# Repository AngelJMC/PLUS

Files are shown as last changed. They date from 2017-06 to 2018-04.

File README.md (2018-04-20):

# Otto DIY +
"Otto DIY with steroids" 

This Repository have all open source files for Otto DIY+ an interactive robot that anyone can make!,
Otto DIY + can make everything that Otto DIY does + Bluetooth + APP + switch + sensors + strength +... anything you might create
Is completely open source, Arduino compatible, 3D printable, once you have all components and tools you will be able to build your own Otto


This is a more advanced version requires some expertise and patience, if you want to start slow as a beginner  please go to [Otto DIY repository](https://github.com/OttoDIY/DIY)

Start by downloading all files here.

### Customized version

This custom version includes:
1. Lithium battery with micro USB charger and 5v step-up module.
2. MG90S servos
3. A touch sensor with two pushbutton.

Video: https://youtu.be/i325EG5CZ8M

## For the hardware
Gather all the off the shelf parts in the BOM file that you'll need for this assembly, then 3d print the latest .stl files and then follow the instruction manual to build your own robot.

## For the programming
1. Download & Install Arduino IDE: https://www.arduino.cc/en/Main/Software also this driver if you have a clone board: http://www.wch.cn/download/CH341SER_EXE.html for PC, or http://www.wch.cn/download/CH341SER_MAC_ZIP.html for MAC
2. Copy all libraries to C:\Users\user\Documents\Arduino\libraries (or wherever your library folder is installed):
3. Open  for example OTTO_smooth_criminal.ino, make sure in tools you have "Board: Arduino Nano" "Processor ATmega328" and your Otto is connected to the corresponding port
4. Upload code to your Otto and will dance!
5. Make your own dance just modify the program using same functions

### Otto DIY + is  design using Autodesk Fusion 360
So is completely parametric and precise to adjust tolerances
[You can modify it for customization](https://gallery.autodesk.com/fusion360/projects/otto-diyplus) or further improvements!

Special thanks to all #Ottobuilders that made and are making this project evolve:
Davor Levstek 
jarsoftelectrical
Juan Felix Mateos
Loreman
Gerardo Barbarov Rostan
Javier Isabel
G4alileo
Obijuan
tritri62
Octavio P Nogueira
Gustavo Reynaga
Rafael López
Frank Lopez
Jason Snow
Pablo E. García Palacios
Marco
Liao Ping Lun
Jayesh Chauhan
If we skip one please tell us!

## License CC-BY-SA
<br /><span xmlns:dct="http://purl.org/dc/terms/" property="dct:title">Otto DIY</span> by <a xmlns:cc="http://creativecommons.org/ns#"  property="cc:attributionName"> [ottodiy.com](http://ottodiy.com) </a> is licensed under a <a rel="license" href="http://creativecommons.org/licenses/by-sa/4.0/">Creative Commons Attribution-ShareAlike 4.0 International License</a>.

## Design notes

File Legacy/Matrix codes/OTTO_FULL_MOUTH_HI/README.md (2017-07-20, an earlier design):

# Otto DIY PLUS

This Repository have all open source files for my version of the popular Otto DIY PLUS with the OTTO welcome on 7219MAX MATRIX LED mouth
The Arduino code is modified from the Zowi robot and original OTTO code, it has modified to work with a MAX 7219 LED MATRIX as as mouth as well as other software adjustments.

Please copy all the files in the Library folder to the Arduino IDE Library folder

The main program is inside the OTTO_FULL_MOUTH_HI folder, ensure you are using the latest version of the Arduino IDE.

Happy roboting....

Otto was inspired by another robot BoB the BiPed and programmed using code from [another open source biped robot Zowi](https://github.com/bqlabs/zowi)

## License CC-BY-SA
<br /><span xmlns:dct="http://purl.org/dc/terms/" property="dct:title">OttoDIY</span> by <a xmlns:cc="http://creativecommons.org/ns#" href="ottobot.org" property="cc:attributionName" rel="cc:attributionURL">ottobot.org</a> is licensed under a <a rel="license" href="http://creativecommons.org/licenses/by-sa/4.0/">Creative Commons Attribution-ShareAlike 4.0 International License</a>.

Otto's differences are in the assembled size (11cm x 7cm x12cm), cleaner integration of components and expressions. 
Using off the shelf and 3D printed parts, simple electronics connections (almost no welding required), and basic coding skills, [you will be able to build your own cute Otto friend in as little as two hours!](http://www.instructables.com/id/Otto-Build-You-Own-Robot-in-Two-Hours/)

### Otto is design using Autodesk 123D Design software 
[You can modify it for customization](http://www.123dapp.com/Project/Otto-build-your-own-robot/5658683) or further improvements!
Gather all the off the shelf parts in the [BOM file] (https://github.com/OttoDIY/Otto/blob/master/OTTO_V02_BOM_STP_STL/OTTO_BOM.xlsx) that you'll need for this assembly, then follow [the instruction manual] (https://github.com/OttoDIY/Otto/blob/master/OTTO_V02_BOM_STP_STL/OTTO_InstructionManual_V02.pdf)

This robot is licensed under a Creative Commons Attribution-ShareAlike 4.0 International License. Please read the LICENSE files for more details.

More info in http://ottobot.org

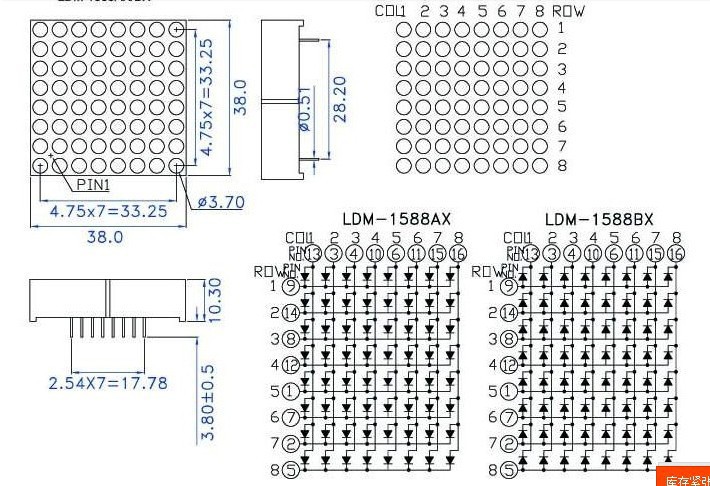
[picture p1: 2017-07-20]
Documents/3-75MM-8-8-red-dot-16P-1588BS-Dimensions-38-38LED-dot-matrix-module.jpg

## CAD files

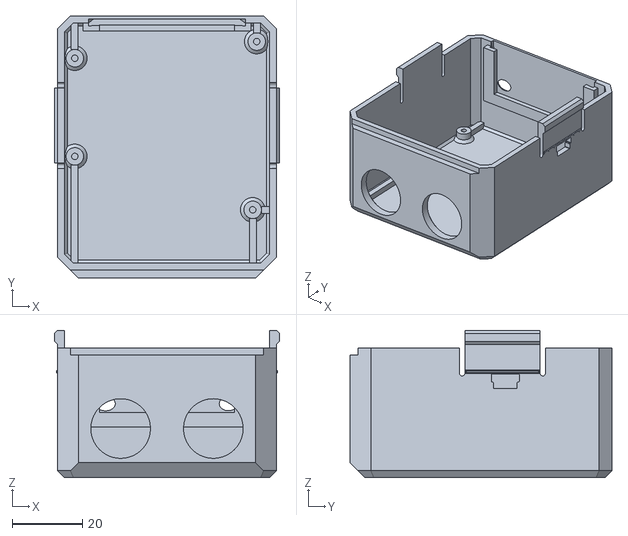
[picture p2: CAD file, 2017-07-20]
3D print/OTTO_Head_MATRIX_MG90S.stl
64.3 x 74.7 x 42.0

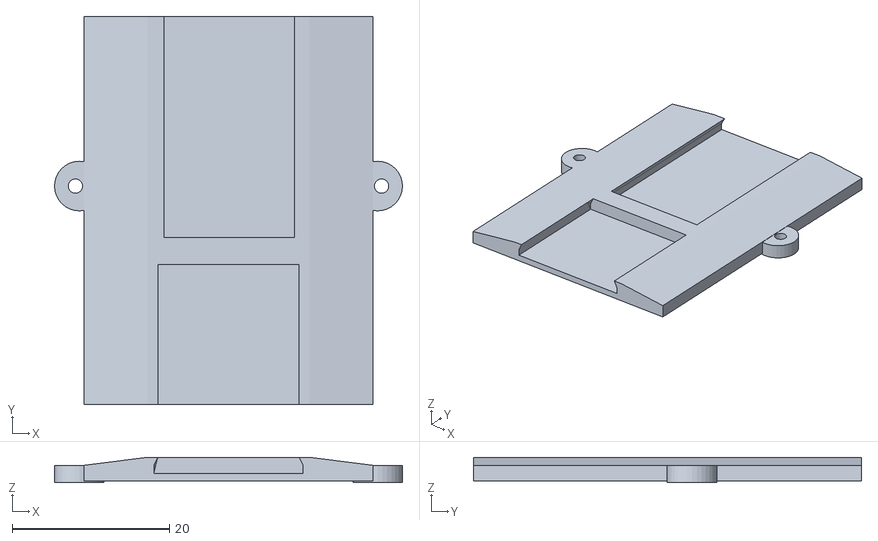
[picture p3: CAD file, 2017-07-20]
3D print/OTTO_battery_MG90S.stl
44.3 x 49.4 x 3.22

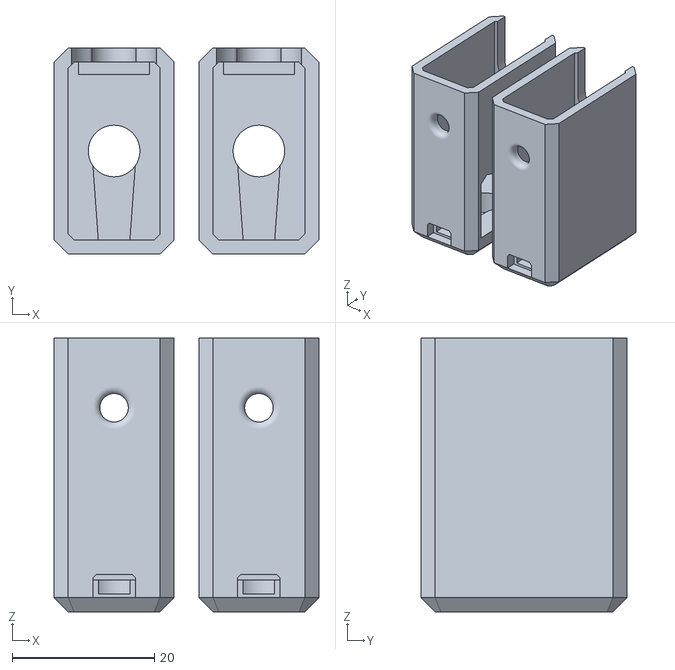
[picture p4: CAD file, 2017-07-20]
3D print/OTTO_legs_MG90s.stl
37.2 x 29.0 x 38.5

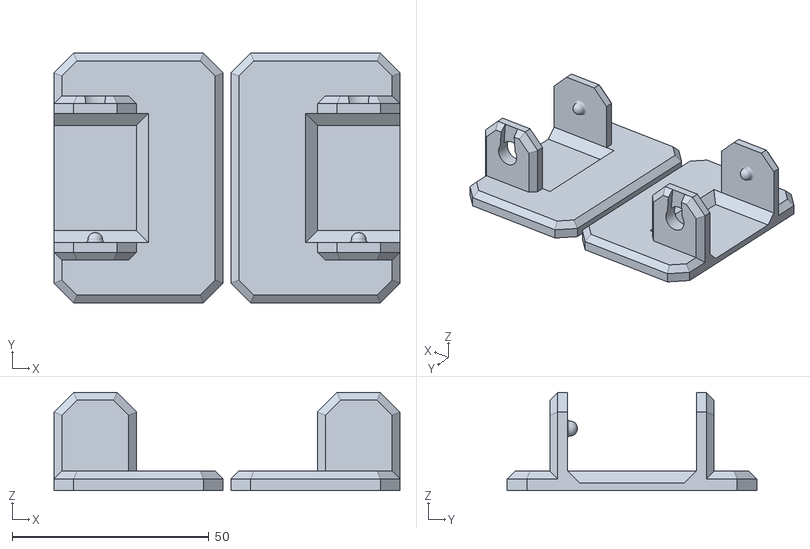
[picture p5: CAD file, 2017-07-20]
3D print/OTTO_feet_MG90S.stl
88.0 x 63.5 x 25.0

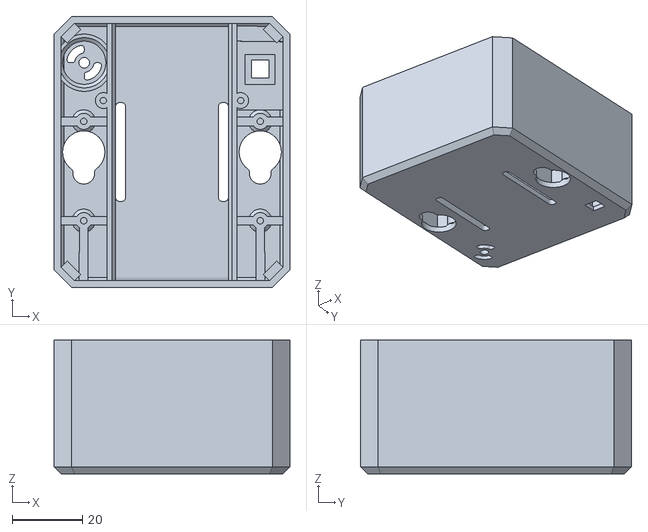
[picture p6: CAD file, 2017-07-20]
3D print/OTTO_Body_MATRIX_MG90S.stl
67.0 x 77.0 x 38.0

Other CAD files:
3D print/Blender3D/OTTO_Body_Matrix_v6.blend
3D print/Blender3D/body.blend
3D print/Blender3D/head.blend

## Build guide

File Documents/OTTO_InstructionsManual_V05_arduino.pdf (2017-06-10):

# DIY

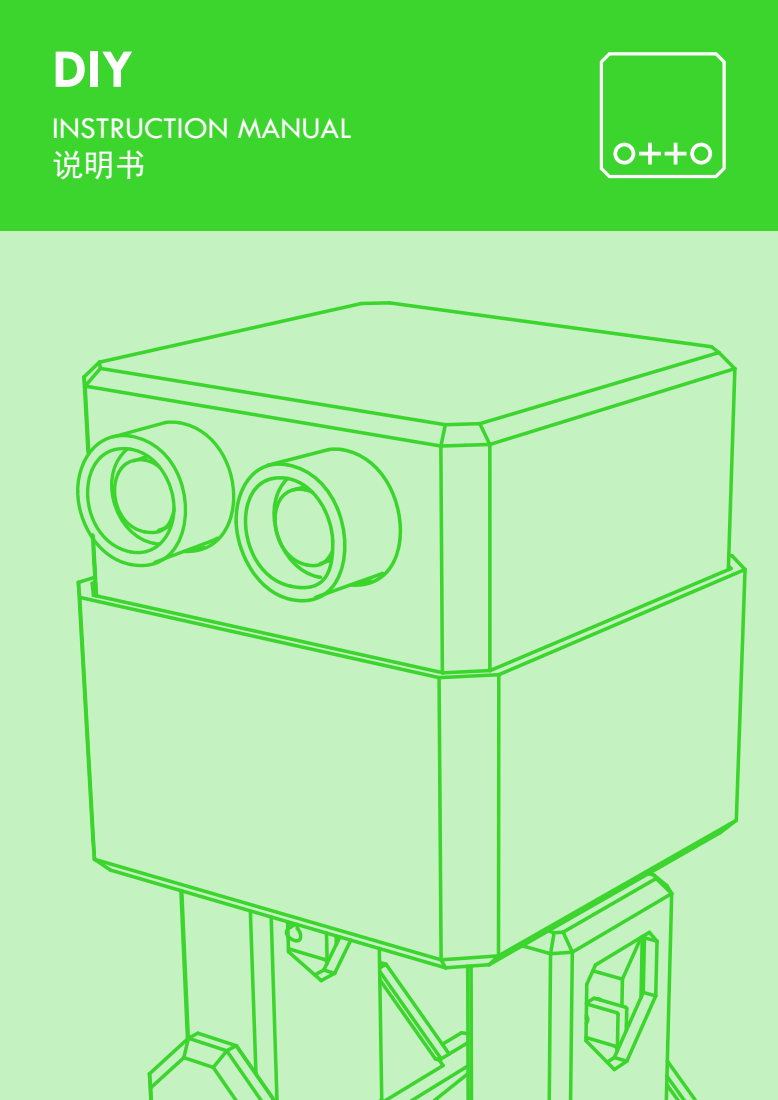
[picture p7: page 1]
INSTRUCTION MANUAL 说明书

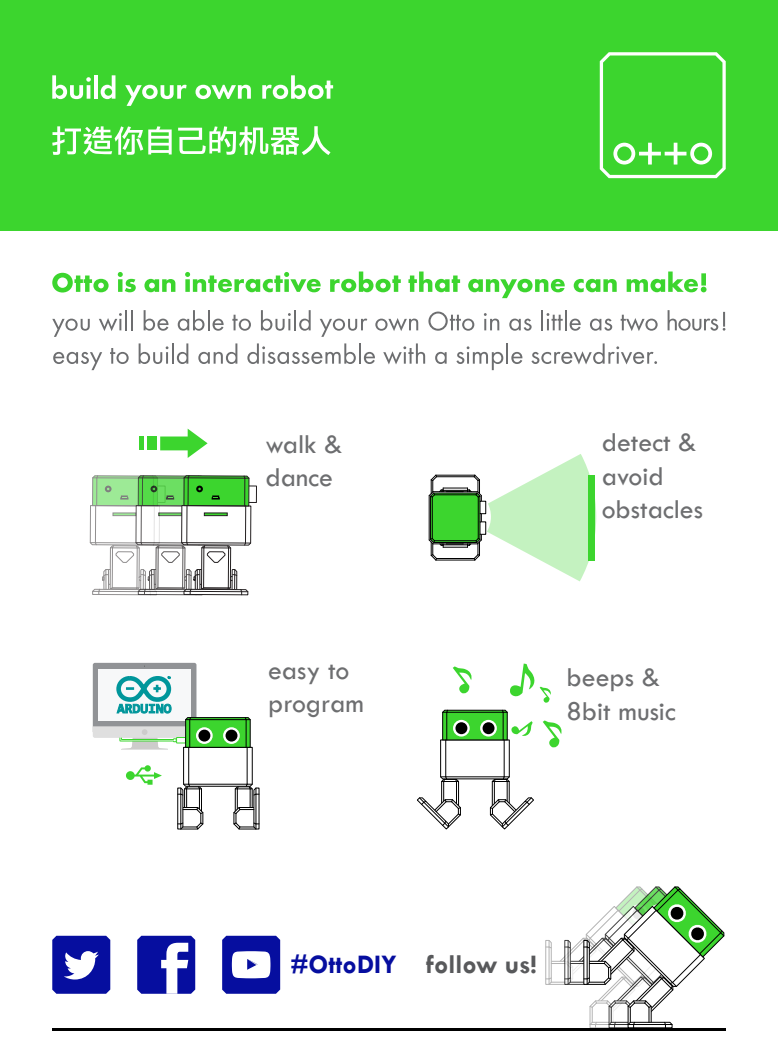
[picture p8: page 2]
beeps & 8bit music; detect & avoid obstacles; walk & dance; easy to program

#OttoDIY follow us!

# PARTS

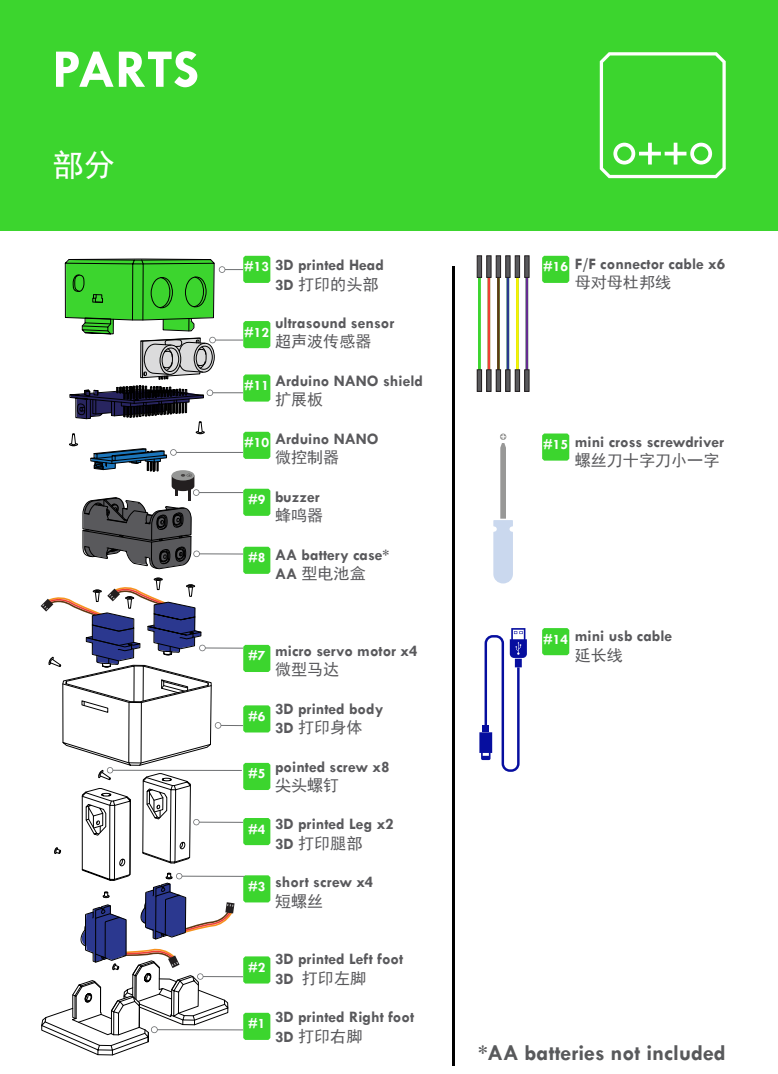
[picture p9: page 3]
#13 3D printed Head 3D 打印的头部; ultrasound sensor 超声波传感器; Arduino NANO shield 扩展板; Arduino NANO 微控制器; buzzer 蜂鸣器; micro servo motor x4 微型马达; 3D printed body 3D 打印身体; pointed screw x8 尖头螺钉; 3D printed Leg x2 3D 打印腿部; short screw x4 短螺丝; 3D printed Left foot 3D 打印左脚; #16 F/F connector cable x6 母对母杜邦线; mini cross screwdriver 螺丝刀十字刀小一字; mini usb cable 延长线

AA battery case*
AA 型电池盒

3D printed Right foot
3D 打印右脚 #1

*AA batteries not included

a

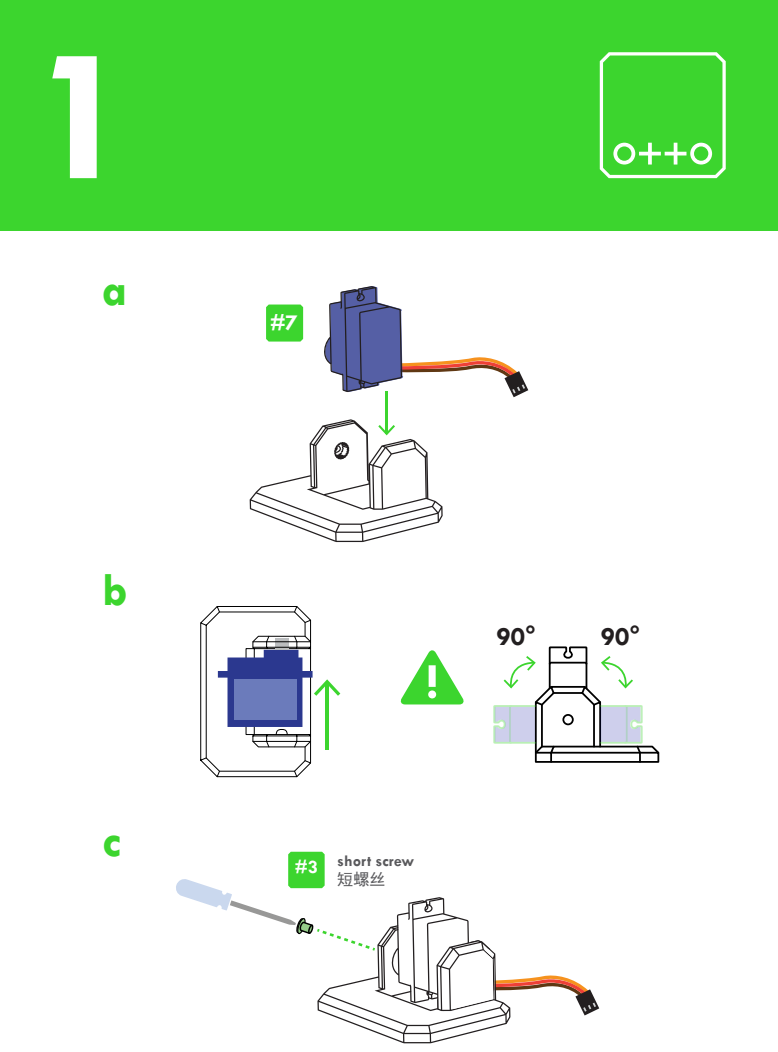
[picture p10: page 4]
short screw 短螺丝

a

a

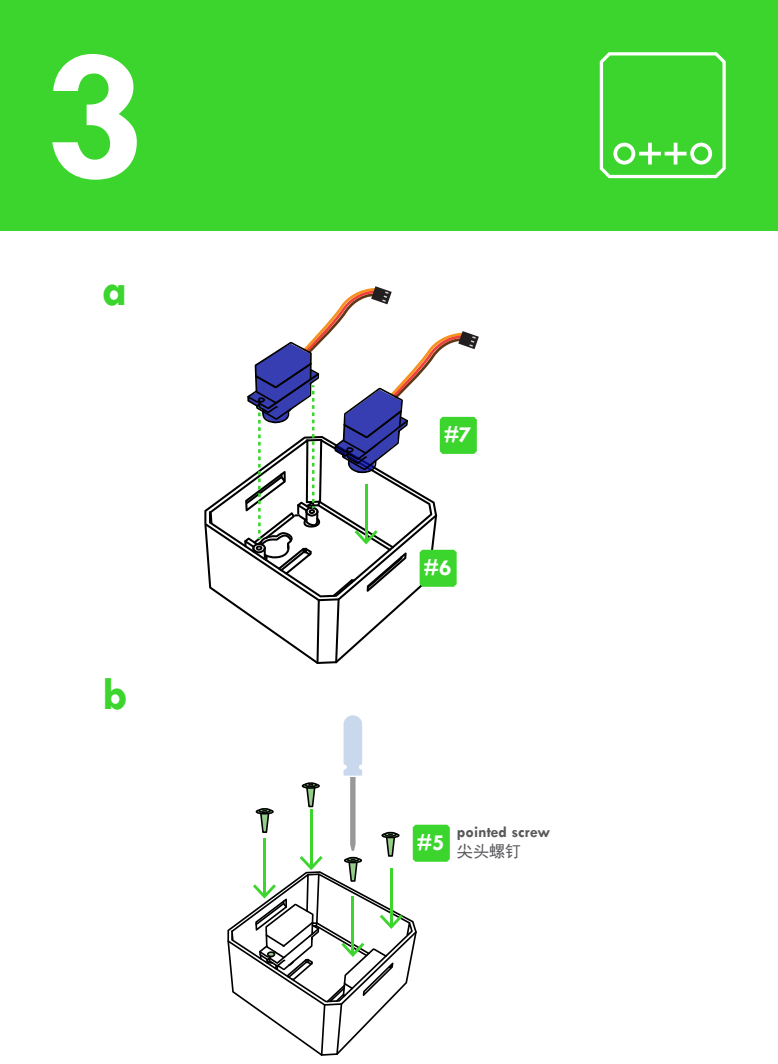
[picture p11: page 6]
#5 pointed screw 尖头螺钉

a

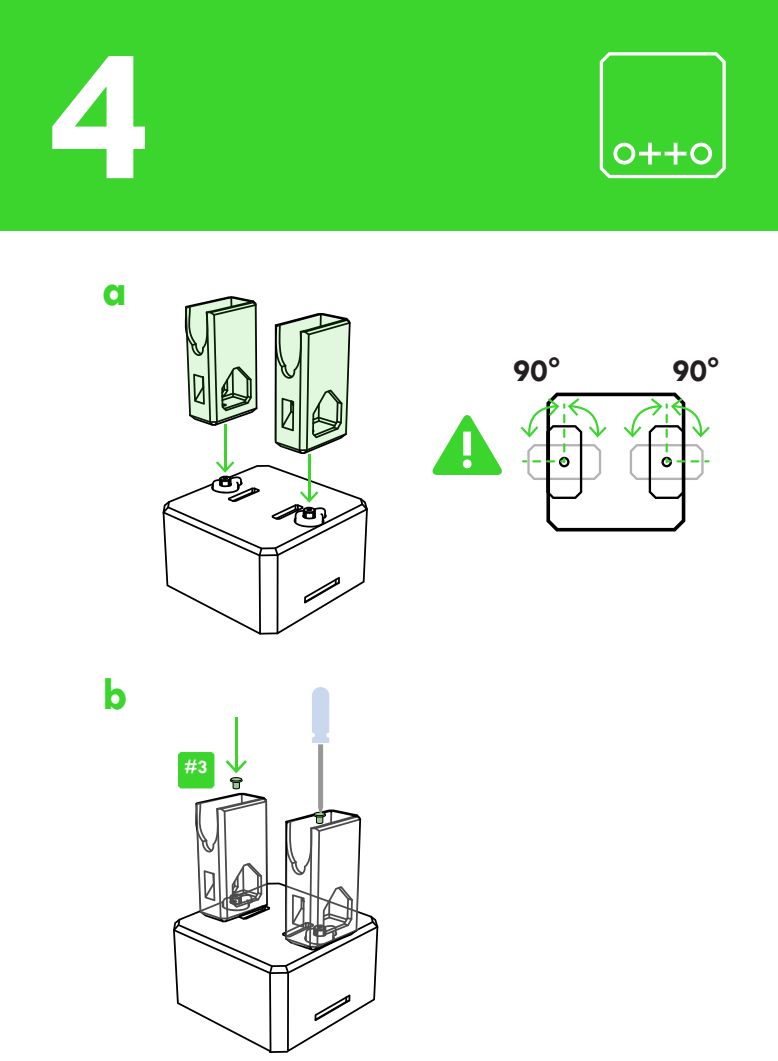
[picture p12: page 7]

ab

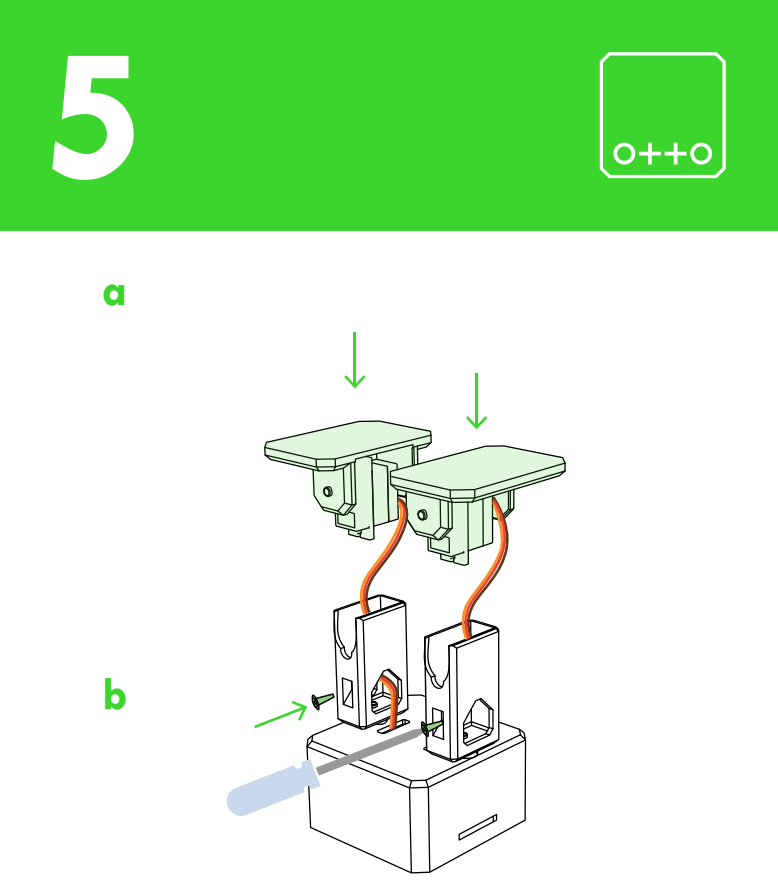
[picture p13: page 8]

ab

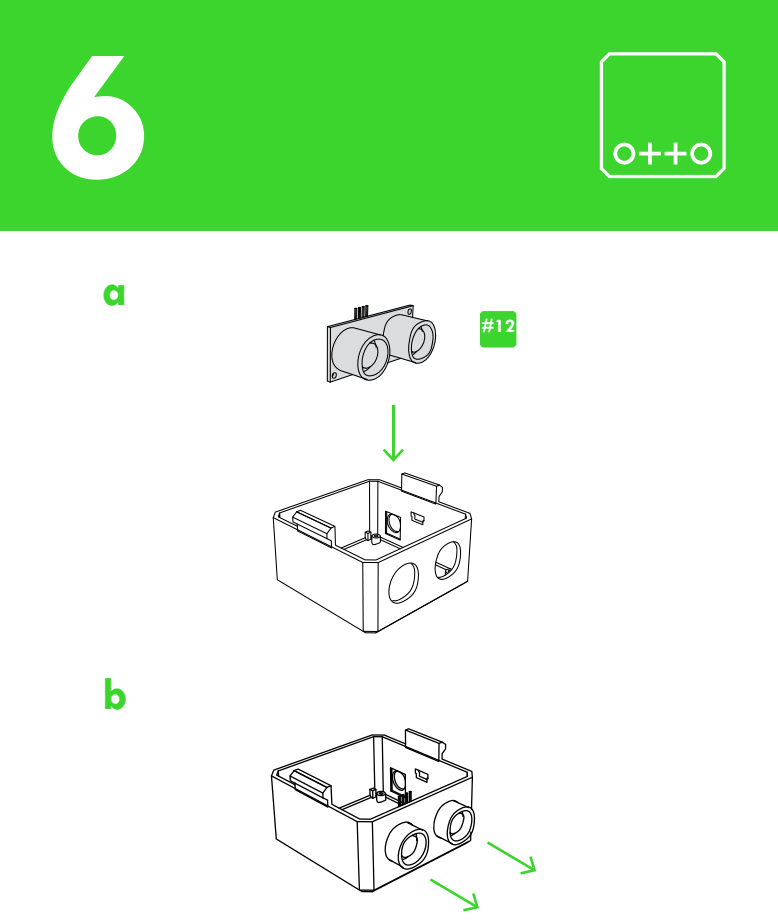
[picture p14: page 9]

ab

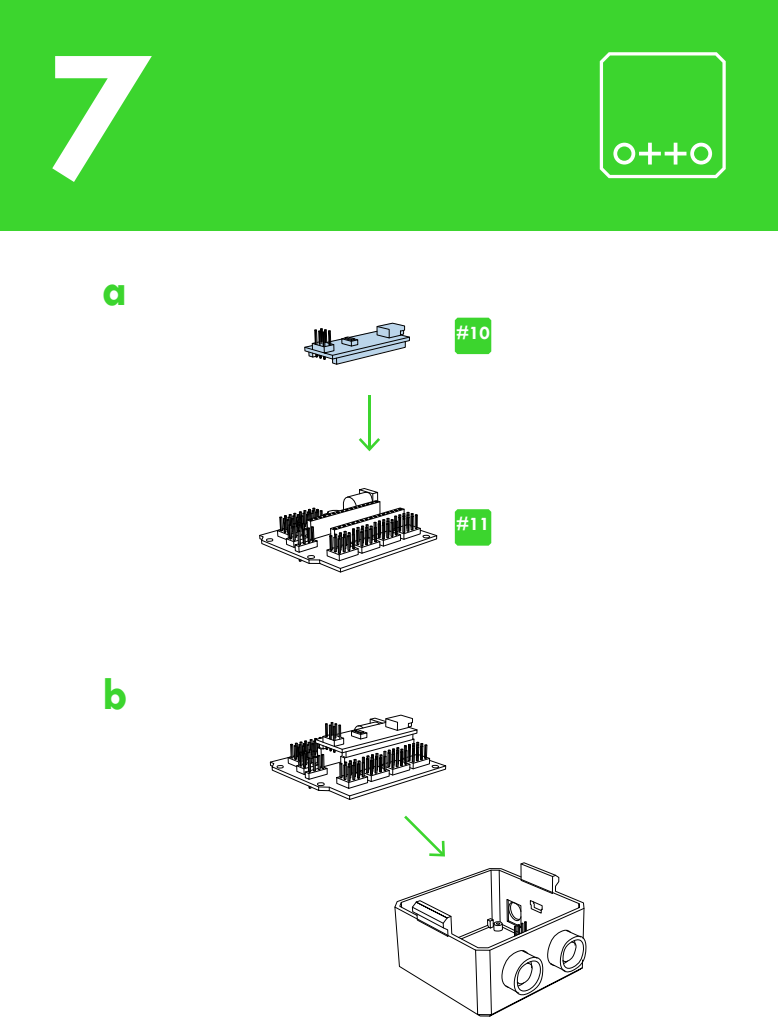
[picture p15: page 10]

ab

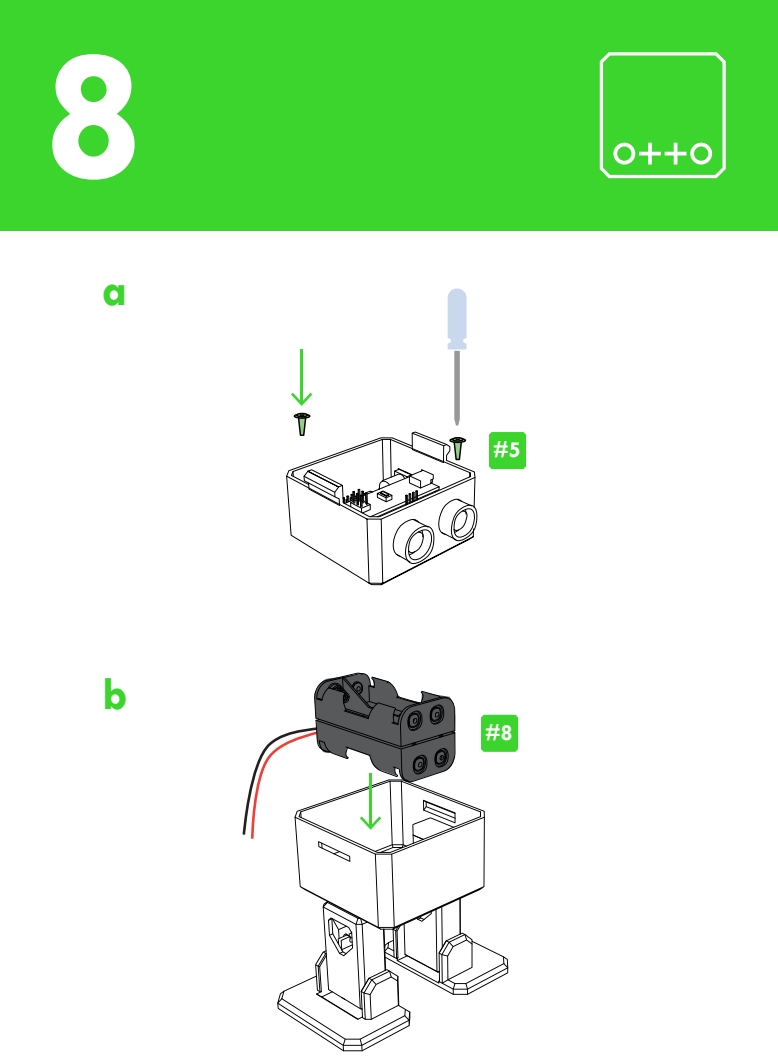
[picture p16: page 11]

*cable colors may vary

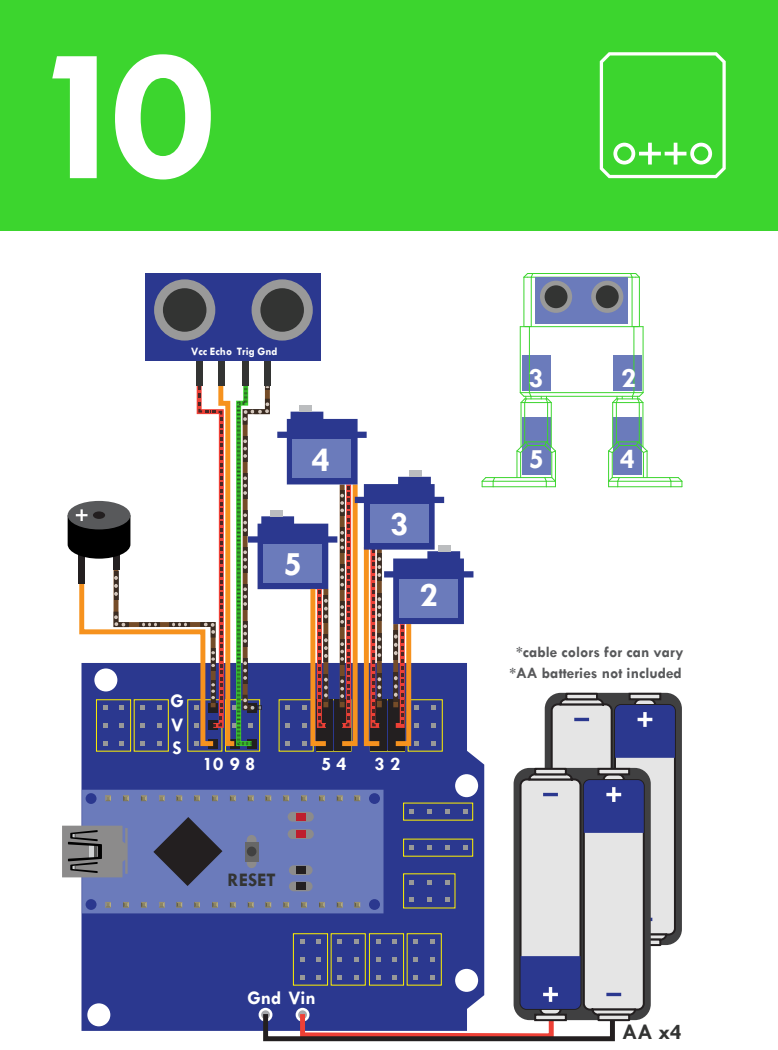
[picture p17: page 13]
RESET; Gnd Vin

Vcc Echo Trig Gnd

*cable colors for can vary
*AA batteries not included

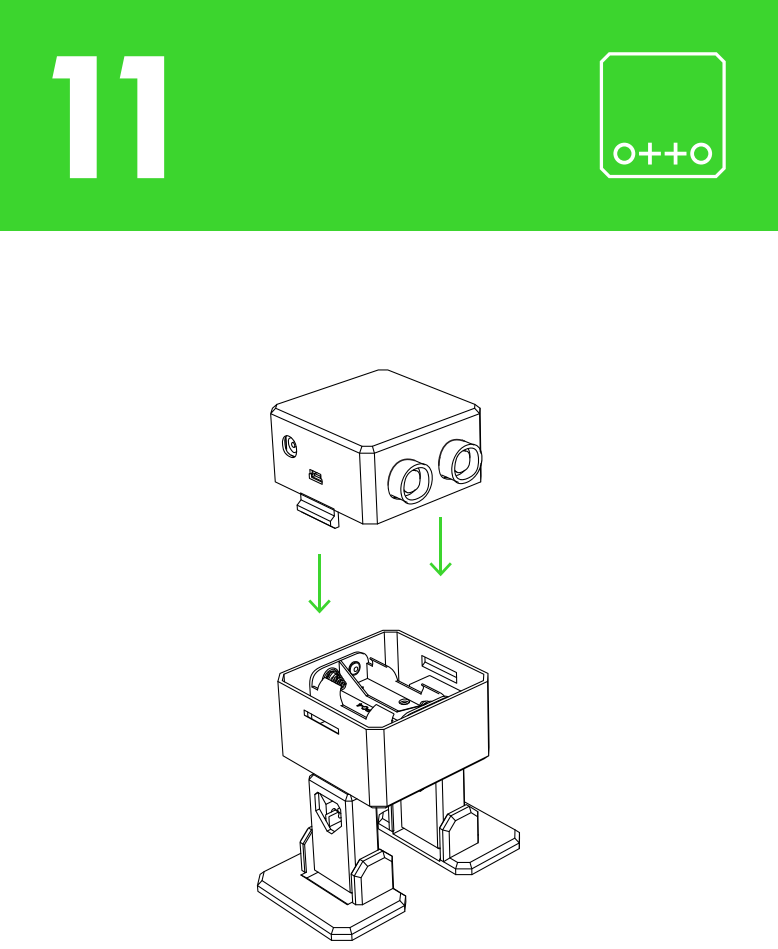
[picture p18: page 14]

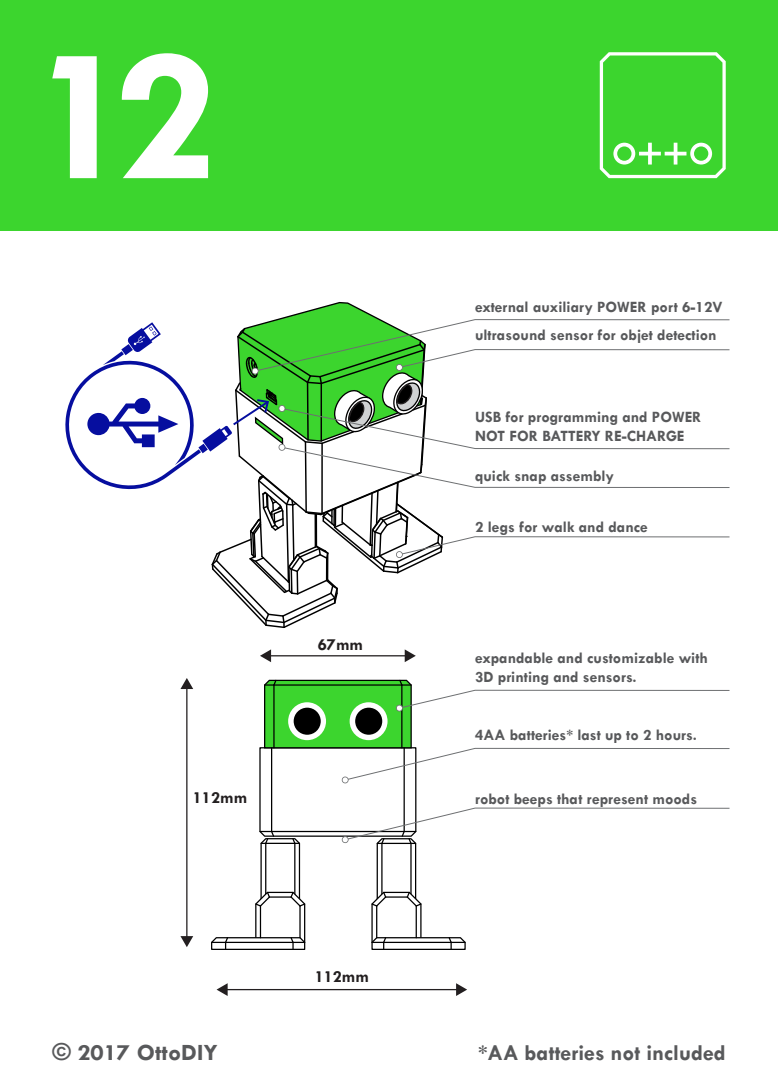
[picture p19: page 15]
© 2017 OttoDIY; *AA batteries not included

external auxiliary POWER port 6-12V
ultrasound sensor for objet detection

USB for programming and POWER
NOT FOR BATTERY RE-CHARGE

quick snap assembly

2 legs for walk and dance

expandable and customizable with
3D printing and sensors.

4AA batteries* last up to 2 hours.

robot beeps that represent moods

# DIY

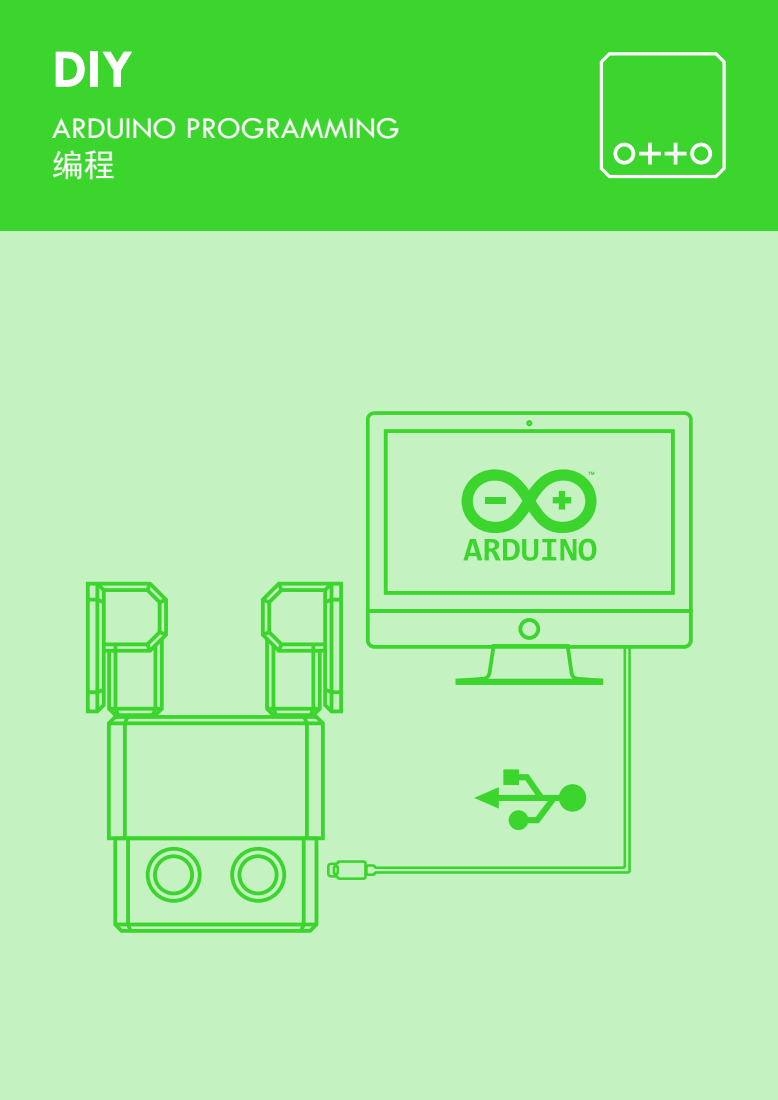
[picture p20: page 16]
ARDUINO PROGRAMMING 编程

a

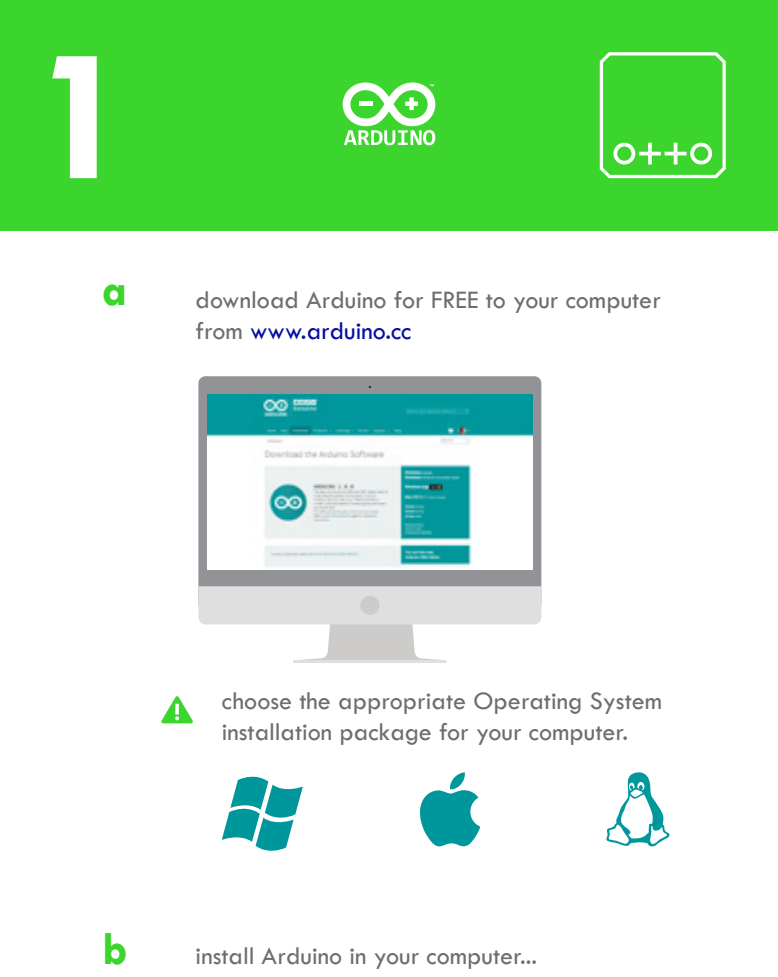
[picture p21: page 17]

download Arduino for FREE to your computer
from www.arduino.cc

choose the appropriate Operating System
installation package for your computer.

install Arduino in your computer...

a

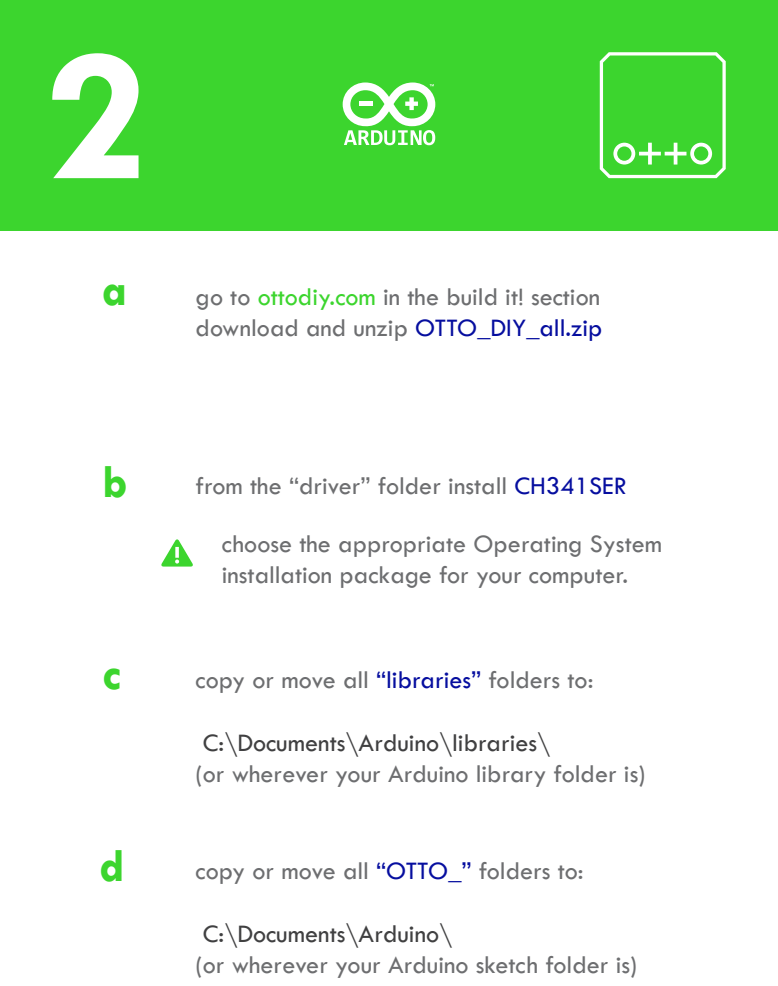
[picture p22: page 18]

go to ottodiy.com in the build it! section
download and unzip OTTO_DIY_all.zip

from the “driver” folder install CH341SER
choose the appropriate Operating System
installation package for your computer.
copy or move all “libraries” folders to:

C:\Documents\Arduino\libraries\
(or wherever your Arduino library folder is)

copy or move all “OTTO_” folders to:

C:\Documents\Arduino\
(or wherever your Arduino sketch folder is)

a

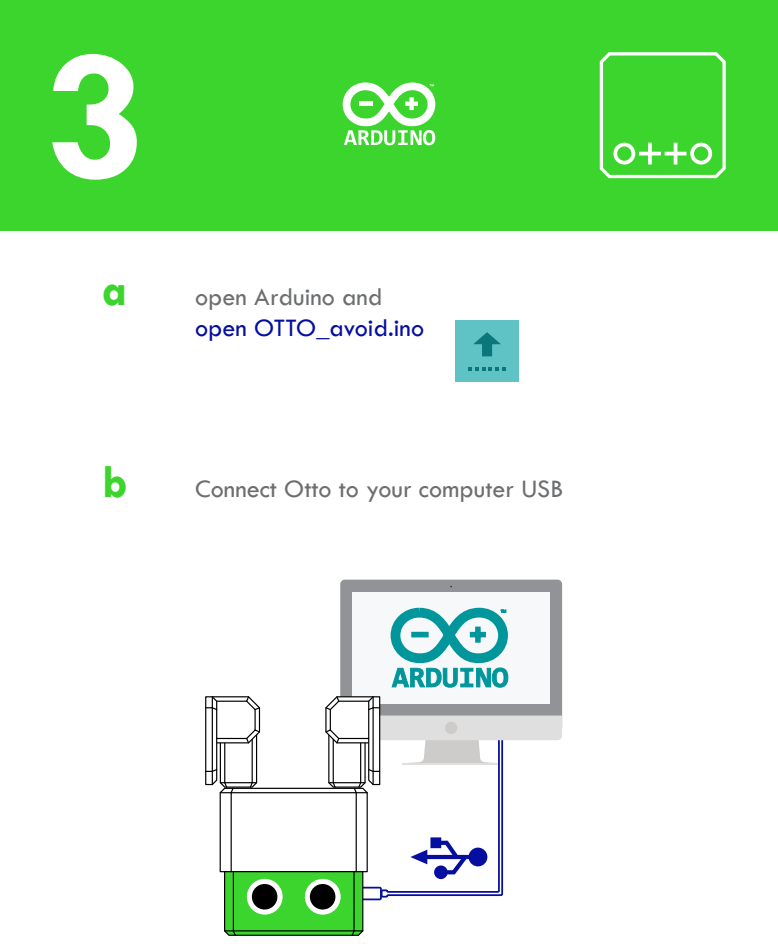
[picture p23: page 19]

open Arduino and
open OTTO_avoid.ino

Connect Otto to your computer USB

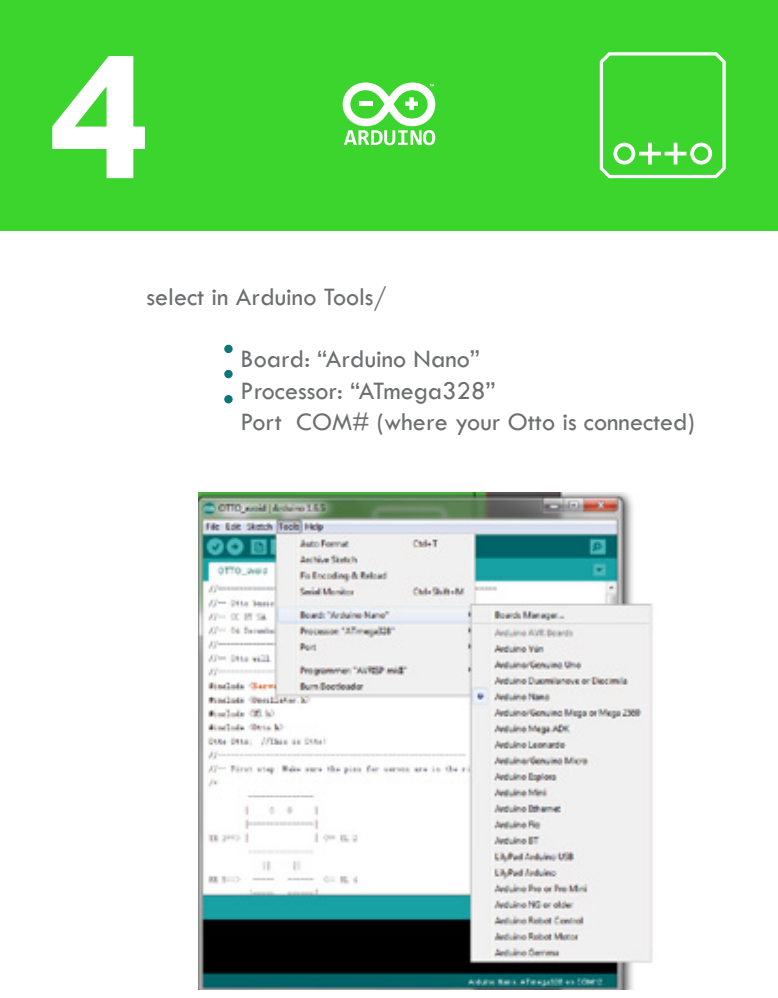
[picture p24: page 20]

select in Arduino Tools/

Board: “Arduino Nano”
Processor: “ATmega328”
Port COM# (where your Otto is connected)

a

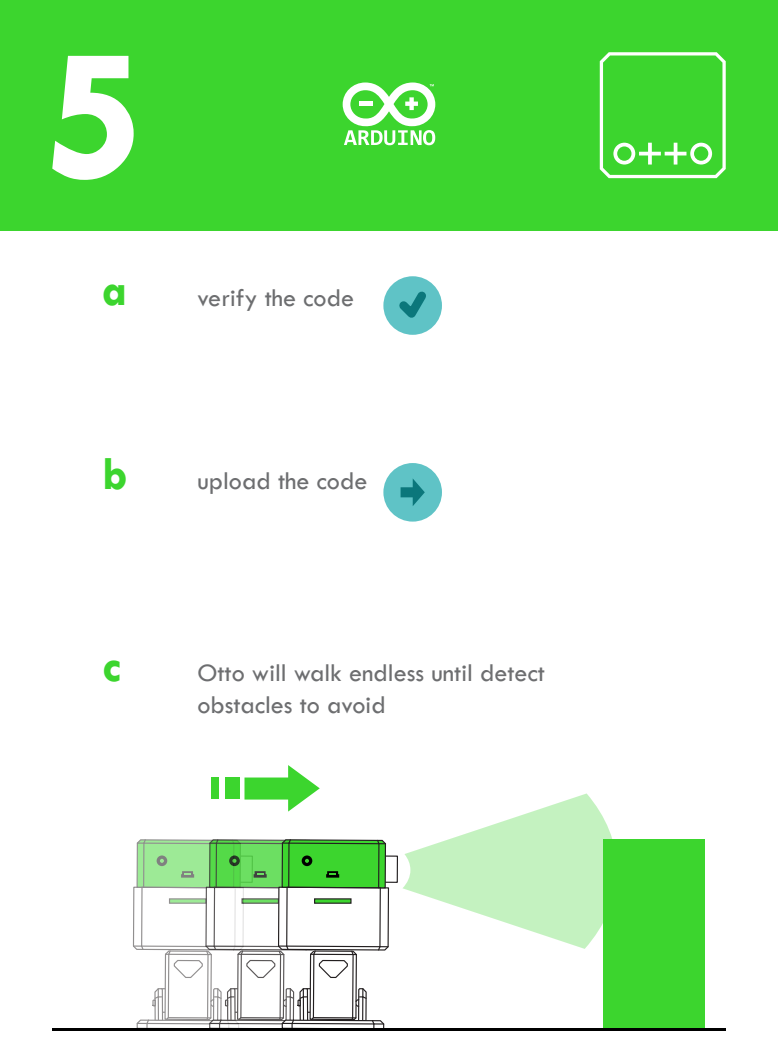
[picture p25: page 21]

verify the code

upload the code

Otto will walk endless until detect
obstacles to avoid

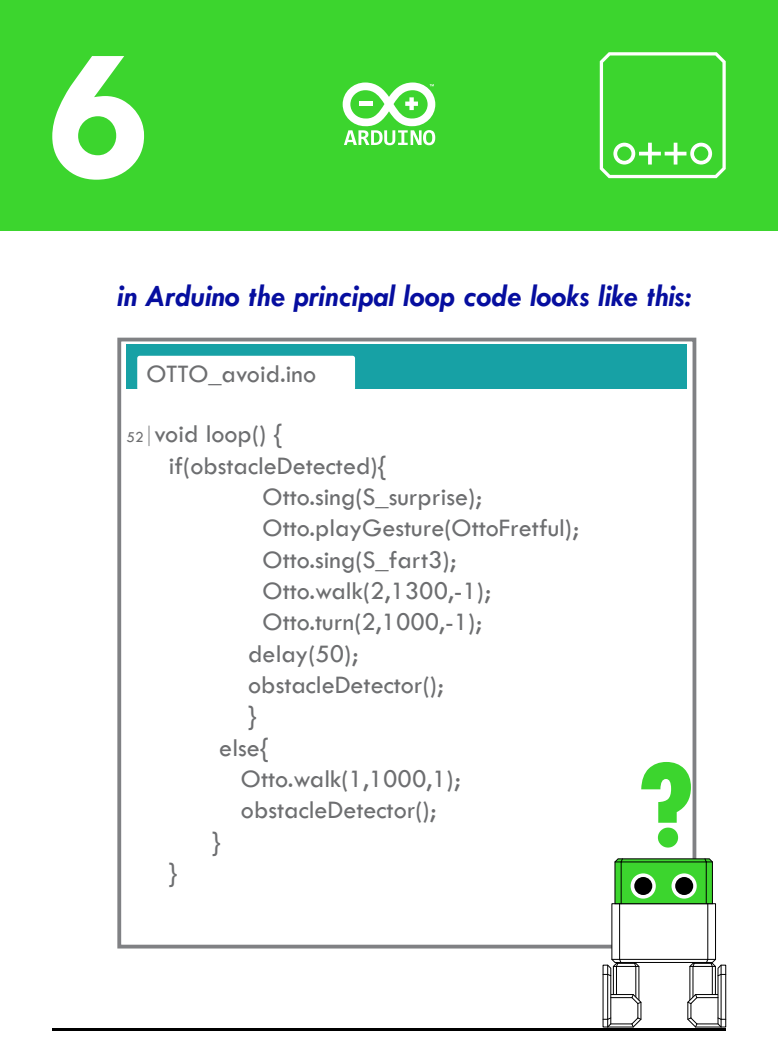
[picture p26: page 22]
void loop() { if(obstacleDetected){ Otto.sing(S_surprise); Otto.playGesture(OttoFretful); Otto.sing(S_fart3); Otto.walk(2,1300,-1); Otto.turn(2,1000,-1); delay(50); obstacleDetector(); } else{ Otto.walk(1,1000,1); obstacleDetector();; OTTO_avoid.ino

in Arduino the principal loop code looks like this:

try change sound:

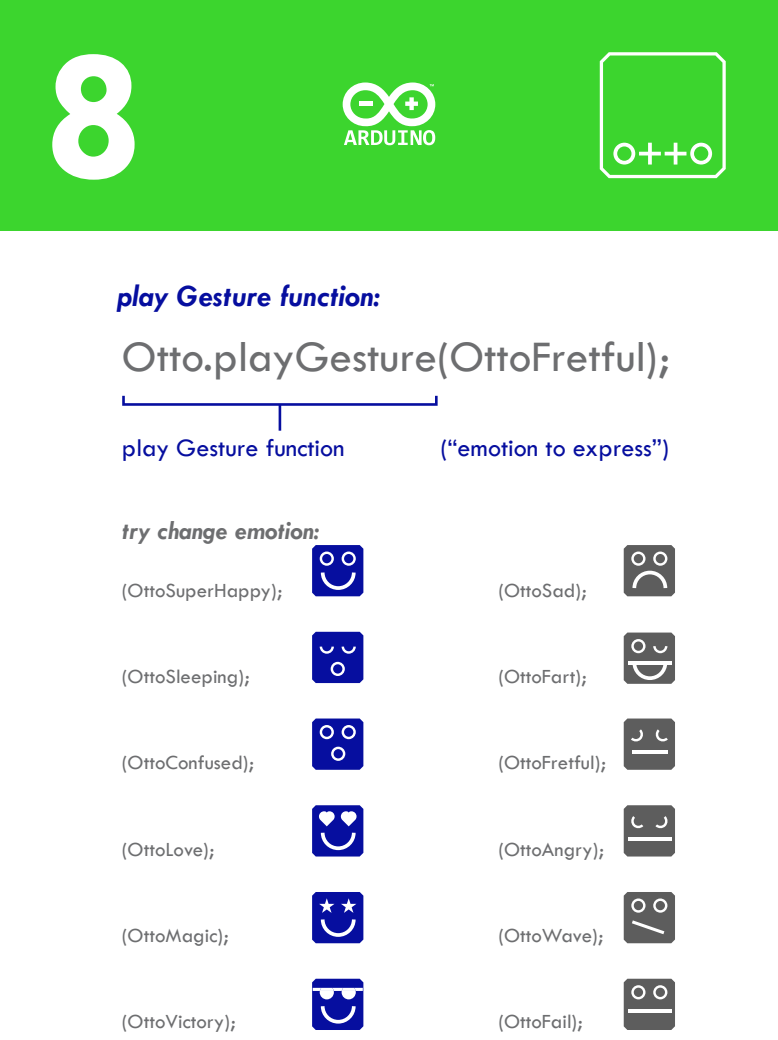
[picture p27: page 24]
(OttoSuperHappy);; (OttoSad);; (OttoSleeping);; (OttoFart);; (OttoConfused);; (OttoFretful);; (OttoLove);; (OttoAngry);; (OttoMagic);; (OttoWave);; (OttoVictory);; (OttoFail);; play Gesture function; (“emotion to express”)

play Gesture function:
Otto.playGesture(OttoFretful);

try change emotion:

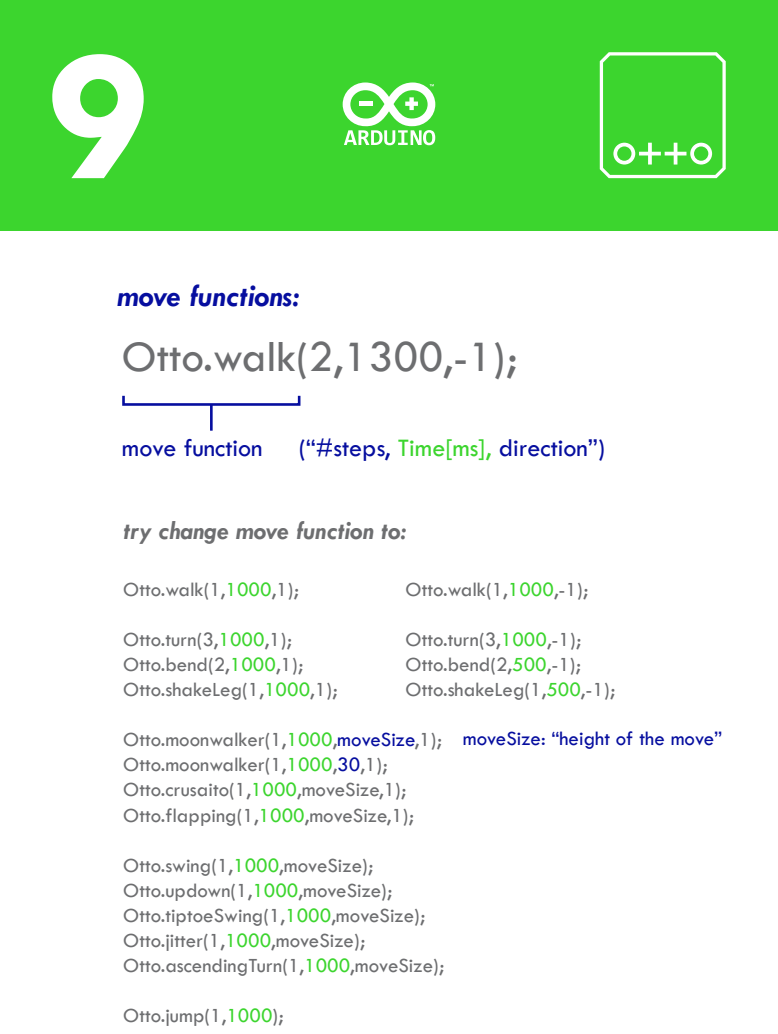
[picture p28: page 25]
move functions: Otto.walk(2,1300,-1);; Otto.walk(1,1000,1);; Otto.walk(1,1000,-1);; Otto.turn(3,1000,1);; Otto.turn(3,1000,-1);; Otto.bend(2,1000,1);; Otto.bend(2,500,-1);; Otto.shakeLeg(1,1000,1);; Otto.shakeLeg(1,500,-1);; Otto.jump(1,1000);

move function (“#steps, Time[ms], direction”)

try change move function to:

Otto.moonwalker(1,1000,moveSize,1);
Otto.moonwalker(1,1000,30,1);
Otto.crusaito(1,1000,moveSize,1);
Otto.flapping(1,1000,moveSize,1);

moveSize: “height of the move”

Otto.swing(1,1000,moveSize);
Otto.updown(1,1000,moveSize);
Otto.tiptoeSwing(1,1000,moveSize);
Otto.jitter(1,1000,moveSize);
Otto.ascendingTurn(1,1000,moveSize);

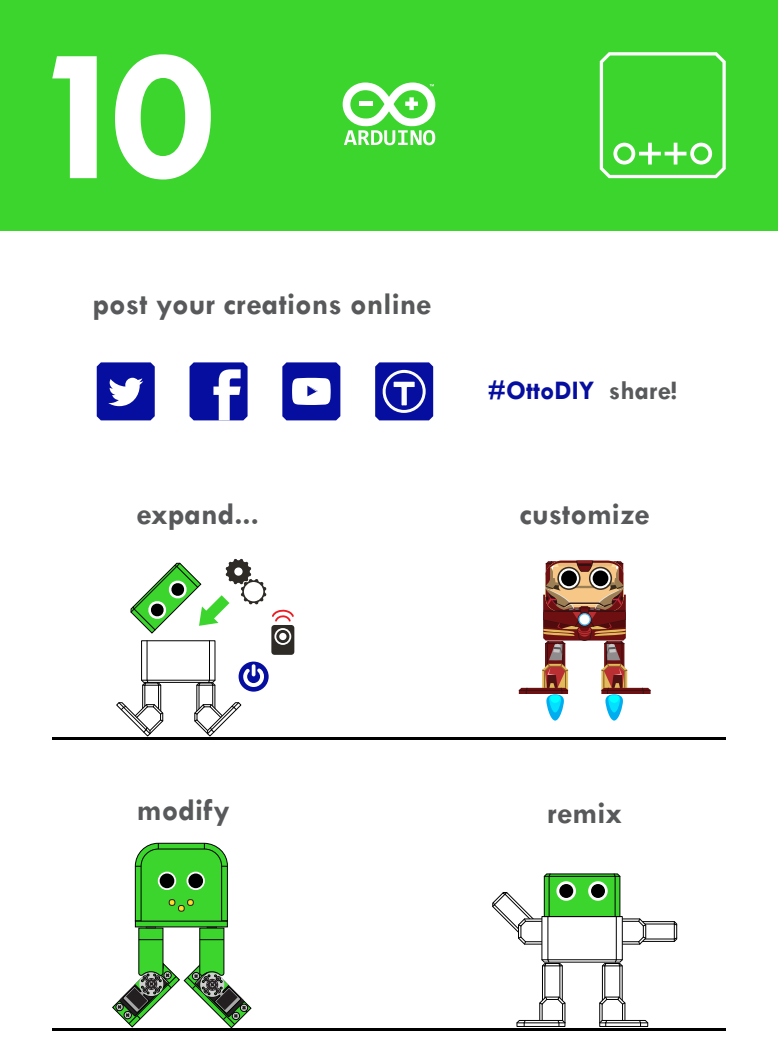
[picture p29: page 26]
#OttoDIY share!; remix; expand...; customize; modify

post your creations online

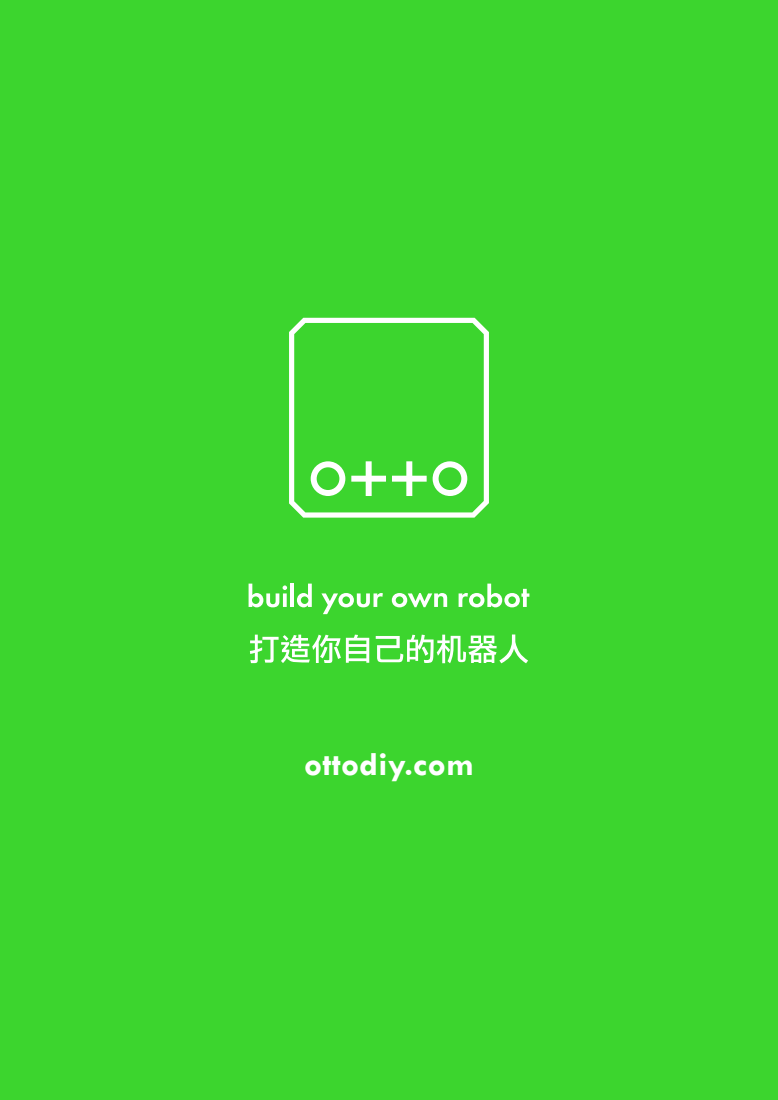
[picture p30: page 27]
ottodiy.com

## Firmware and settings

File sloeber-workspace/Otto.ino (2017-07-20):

//----------------------------------------------------------------
//-- Zowi basic firmware v2 adapted to Otto
//-- (c) BQ. Released under a GPL licencse
//-- 04 December 2015
//-- Authors:  Anita de Prado: ana.deprado@bq.com
//--           Jose Alberca:   jose.alberca@bq.com
//--           Javier Isabel:  javier.isabel@bq.com
//--           Juan Gonzalez (obijuan): juan.gonzalez@bq.com
//--           Irene Sanz : irene.sanz@bq.com
//-----------------------------------------------------------------
//-- Experiment with all the features that Otto has thanks to Zowi!
//-----------------------------------------------------------------
//-- FEBRUARY 2017: modified for OTTO with MAX7219 MATRIX LED module
//-- allows OTTO to work with ZOWI APP
//-- MARCH 2017: added personal welcome..
//-- Jason Snow
//-----------------------------------------------------------------

//#include <Servo.h>
//#include <Oscillator.h>
//#include <EEPROM.h>
#include <BatReader.h>
#include <US.h>
#include "MaxMatrix.h"
MaxMatrix ledmatrix=MaxMatrix(12,10,11, 1); //PIN  12=DIN, PIN 10=CS, PIN 11=CLK

//-- Library to manage external interruptions
#include <EnableInterrupt.h>

//-- Library to manage serial commands
#include <OttoSerialCommand.h>
OttoSerialCommand SCmd;  //The SerialCommand object

//-- Otto Library
#include <Otto.h>
Otto otto;  //This is Otto!

//---------------------------------------------------------
//-- First step: Configure the pins where the servos are attached
/*
         ---------------
        |     O   O     |
        |---------------|
YR 3==> |               | <== YL 2
         ---------------
            ||     ||
            ||     ||
RR 5==>   -----   ------  <== RL 4
         |-----   ------|
*/

  #define PIN_YL 2 //servo[0]
  #define PIN_YR 3 //servo[1]
  #define PIN_RL 4 //servo[2]
  #define PIN_RR 5 //servo[3]

//---Otto Buttons
#define PIN_SecondButton 6
#define PIN_ThirdButton 7
// buzzer connected to pin 13

///////////////////////////////////////////////////////////////////
//-- Global Variables -------------------------------------------//
///////////////////////////////////////////////////////////////////

const char programID[]="OttoPlus_v1.2"; //Each program will have a ID

const char name_fac='$'; //Factory name
const char name_fir='#'; //First name

//-- Movement parameters
int T=1000;              //Initial duration of movement
int moveId=0;            //Number of movement
int moveSize=15;         //Asociated with the height of some movements

//---------------------------------------------------------
//-- Otto has 5 modes:
//--    * MODE = 0: Otto is awaiting
//--    * MODE = 1: Dancing mode!
//--    * MODE = 2: Obstacle detector mode
//--    * MODE = 3: Noise detector mode
//--    * MODE = 4: OttoPAD or any Teleoperation mode (listening SerialPort).
//---------------------------------------------------------
volatile int MODE=0; //State of Otto in the principal state machine.

volatile bool buttonPushed=false;  //Variable to remember when a button has been pushed
volatile bool buttonAPushed=false; //Variable to remember when A button has been pushed
volatile bool buttonBPushed=false; //Variable to remember when B button has been pushed

unsigned long previousMillis=0;

int randomDance=0;
int randomSteps=0;

bool obstacleDetected = false;


///////////////////////////////////////////////////////////////////
//-- Setup ------------------------------------------------------//
///////////////////////////////////////////////////////////////////
void setup(){

  //Serial communication initialization
  Serial.begin(115200);

  pinMode(PIN_SecondButton,INPUT); //D6 - ensure pull-down resistors are used
  pinMode(PIN_ThirdButton,INPUT); //D7 - ensure pull-down resistors are used

  //Set the servo pins
  otto.init(PIN_YL,PIN_YR,PIN_RL,PIN_RR,true);

  //Uncomment this to set the servo trims manually and save on EEPROM
    //otto.setTrims(TRIM_YL, TRIM_YR, TRIM_RL, TRIM_RR);
    //otto.saveTrimsOnEEPROM(); //Uncomment this only for one upload when you finaly set the trims.
// set up Matrix display
  ledmatrix.init();
  ledmatrix.setIntensity(1);
  //Set a random seed
  randomSeed(analogRead(A6));

  //Interruptions
  enableInterrupt(PIN_SecondButton, secondButtonPushed, RISING);
  enableInterrupt(PIN_ThirdButton, thirdButtonPushed, RISING);

  //Setup callbacks for SerialCommand commands
  SCmd.addCommand("S", receiveStop);      //  sendAck & sendFinalAck
  SCmd.addCommand("L", receiveLED);       //  sendAck & sendFinalAck
  SCmd.addCommand("T", recieveBuzzer);    //  sendAck & sendFinalAck
  SCmd.addCommand("M", receiveMovement);  //  sendAck & sendFinalAck
  SCmd.addCommand("H", receiveGesture);   //  sendAck & sendFinalAck
  SCmd.addCommand("K", receiveSing);      //  sendAck & sendFinalAck
  SCmd.addCommand("C", receiveTrims);     //  sendAck & sendFinalAck
  SCmd.addCommand("G", receiveServo);     //  sendAck & sendFinalAck
  SCmd.addCommand("R", receiveName);      //  sendAck & sendFinalAck

  SCmd.addCommand("E", requestName);
  SCmd.addCommand("D", requestDistance);
  SCmd.addCommand("N", requestNoise);
  SCmd.addCommand("B", requestBattery); // doesn't function - needs work
  SCmd.addCommand("I", requestProgramId);
  SCmd.addDefaultHandler(receiveStop);



  //Otto wake up!
  otto.sing(S_connection);
  otto.home();


  //If Otto's name is '&' (factory name) means that is the first time this program is executed.
  //This first time, Otto mustn't do anything. Just born at the factory!
  //5 = EEPROM address that contains first name character
  if (EEPROM.read(5)==name_fac){

    EEPROM.put(5, name_fir); //From now, the name is '#'
    EEPROM.put(6, '\0');
    otto.putMouth(culito);

    while(true){
       delay(1000);
    }
  }


  //Send Otto name, programID & battery level.
  requestName();
  delay(50);
  //requestProgramId();
  delay(50);
  //requestBattery();

  //Checking battery
  //OttoLowBatteryAlarm();


 // Animation Uuuuuh - A little moment of initial surprise
 //-----
  for(int i=0; i<2; i++){
      for (int i=0;i<8;i++){
        if(buttonPushed){break;}
        otto.putAnimationMouth(littleUuh,i);
        delay(150);
      }
  }



  //Smile for a happy Otto :)
  if(!buttonPushed){
    otto.putMouth(smile);
    otto.sing(S_happy);
    delay(200);
  }


  //If Otto's name is '#' means that Otto hasn't been baptized
  //In this case, Otto does a longer greeting
  //5 = EEPROM address that contains first name character
  if (EEPROM.read(5)==name_fir){

    if(!buttonPushed){
        otto.jump(1,700);
        delay(200);
    }

    if(!buttonPushed){
        otto.shakeLeg(1,T,1);
    }

    if(!buttonPushed){
        otto.putMouth(smallSurprise);
        otto.swing(2,800,20);
        otto.home();
    }
  }


  if(!buttonPushed){
    otto.putMouth(happyOpen);
  }
  otto.putMouth(culito);

  previousMillis = millis();

}



///////////////////////////////////////////////////////////////////
//-- Principal Loop ---------------------------------------------//
///////////////////////////////////////////////////////////////////
void loop() {


  if (Serial.available()>0 && MODE!=4){

    MODE=4;

    otto.putMouth(MODE);

        int showTime = 2000;
        while((showTime>0)){ //Wait to show the MODE number

            showTime-=10;
            delay(10);
        }

    otto.putMouth(happyOpen);

    //Disable Pin Interruptions
    disableInterrupt(PIN_SecondButton);
    disableInterrupt(PIN_ThirdButton);

    buttonPushed=false;
  }


  //First attemp to initial software
  if (buttonPushed){
	  otto.putMouth(smallSurprise);
    //otto.home();

    delay(100); //Wait for all buttons
    otto.sing(S_buttonPushed);
    delay(200); //Wait for all buttons

    if      ( buttonAPushed && !buttonBPushed){
    	if(MODE==1){
    		MODE = 0;
    		previousMillis=millis();
    	}
    	else{
    		MODE = 1;
    		otto.sing(S_mode1);
    	}
    }

    else if (!buttonAPushed && buttonBPushed){
    	if(MODE==2){
    		MODE = 0;
    		previousMillis=millis();
    	}
    	else{
    		MODE=2;
    		otto.sing(S_mode2);
    	}
    }

    else if ( buttonAPushed && buttonBPushed){
    	if(MODE==3){
    		MODE = 0;
    		previousMillis=millis();
    	}
    	else{
    		MODE=3;
    		otto.sing(S_mode3);
    	}
    }

    otto.putMouth(MODE);

    int showTime = 2000;
    while((showTime>0)){ //Wait to show the MODE number

        showTime-=10;
        delay(10);
    }

    otto.putMouth(happyOpen);

    buttonPushed=false;
    buttonAPushed=false;
    buttonBPushed=false;

  }



    switch (MODE) {

      //-- MODE 0 - otto is awaiting
      //---------------------------------------------------------
      case 0:

        //Every 60 seconds in this mode, Otto falls asleep
        if (millis()-previousMillis>=60000){
            OttoSleeping_withInterrupts(); //ZZzzzzz...
            previousMillis=millis();
        }

        break;


      //-- MODE 1 - Dance Mode!
      //---------------------------------------------------------
      case 1:

        randomDance=random(5,21); //5,20
        if((randomDance>14)&&(randomDance<19)){
            randomSteps=1;
            T=1600;
        }
        else{
            randomSteps=random(3,6); //3,5
            T=1000;
        }

        otto.putMouth(random(10,21));

        for (int i=0;i<randomSteps;i++){
        	if(buttonPushed){break;}
        	move(randomDance);
        }
        break;


      //-- MODE 2 - Obstacle detector mode
      //---------------------------------------------------------
      case 2:

        if(obstacleDetected){

            if(buttonPushed){break;}
              otto.putMouth(bigSurprise);
              otto.sing(S_surprise);
              otto.jump(5, 500);


            if(buttonPushed){break;}
              otto.putMouth(confused);
              otto.sing(S_cuddly);


            //Otto takes two steps back
            for(int i=0;i<3;i++){
              if(buttonPushed){break;}
              otto.walk(1,1300,-1);
            }

            delay(100);
            obstacleDetector();
            delay(100);


           //If there are no obstacles and no button is pressed, Otto shows a smile
           if((obstacleDetected)||(buttonPushed)){break;}
           else{
              otto.putMouth(smile);
              delay(50);
              obstacleDetector();
           }


           //If there are no obstacles and no button is pressed, Otto shows turns left
           for(int i=0; i<3; i++){
              if((obstacleDetected)||(buttonPushed)){break;}
              else{
                  otto.turn(1,1000,1);
                  obstacleDetector();
              }
           }

            //If there are no obstacles and no button is pressed, Otto is happy
            if((obstacleDetected)||(buttonPushed)){break;}
            else{
                otto.home();
                otto.putMouth(happyOpen);
                otto.sing(S_happy_short);
                delay(200);
            }


        }
        else{

            otto.walk(1,1000,1); //Otto walk straight
            obstacleDetector();
        }

        break;


      //-- MODE 3 - Noise detector mode
      //---------------------------------------------------------
      case 3:
        if (otto.getNoise()>=1000){ //740

          delay(50);  //Wait for the possible 'lag' of the button interruptions.
                      //Sometimes, the noise sensor detect the button before the interruption takes efect

          if(buttonPushed){break;}
            otto.putMouth(bigSurprise);
            otto.sing(S_OhOoh);

		  if(buttonPushed){break;}
			otto.putMouth(random(10,21));
			randomDance=random(5,21);
			move(randomDance);
			otto.home();
			delay(500); //Wait for possible noise of the servos while get home

          if(!buttonPushed){break;}
          	otto.putMouth(happyOpen);

        }
        break;


      //-- MODE 4 - OttoPAD or any Teleoperation mode (listening SerialPort)
      //---------------------------------------------------------
      case 4:

        SCmd.readSerial();

        //If Otto is moving yet
        if (otto.getRestState()==false){
          move(moveId);
        }

        break;


      default:
          MODE=4;
          break;
    }



}



///////////////////////////////////////////////////////////////////
//-- Functions --------------------------------------------------//
///////////////////////////////////////////////////////////////////

//-- Function executed when second button is pushed
void secondButtonPushed(){

    buttonAPushed=true;
    buttonPushed=true;
}

//-- Function executed when third button is pushed
void thirdButtonPushed(){

    buttonBPushed=true;
    buttonPushed=true;
}


//-- Function to read distance sensor & to actualize obstacleDetected variable
void obstacleDetector(){

   int distance = otto.getDistance();

        if(distance<20){
          obstacleDetected = true;
        }else{
          obstacleDetected = false;
        }
}


//-- Function to receive Stop command.
void receiveStop(){

    sendAck();
    otto.home();
    sendFinalAck();

}


//-- Function to receive LED commands
void receiveLED(){

    //sendAck & stop if necessary
    sendAck();
    otto.home();

    //Examples of receiveLED Bluetooth commands
    //L 000000001000010100100011000000000
    //L 001111111111111111111111111111111 (todos los LED encendidos)
    unsigned long int matrix;
    char *arg;
    char *endstr;
    arg=SCmd.next();
    //Serial.println (arg);
    if (arg != NULL) {
      matrix=strtoul(arg,&endstr,2);    // Converts a char string to unsigned long integer
      otto.putMouth(matrix,false);
    }else{
      otto.putMouth(xMouth);
      delay(2000);
      otto.clearMouth();
    }

    sendFinalAck();

}


//-- Function to receive buzzer commands
void recieveBuzzer(){
  
    //sendAck & stop if necessary
    sendAck();
    otto.home();

    bool error = false;
    int frec;
    int duration;
    char *arg;

    arg = SCmd.next();
    if (arg != NULL) { frec=atoi(arg); }    // Converts a char string to an integer
    else {error=true;}

    arg = SCmd.next();
    if (arg != NULL) { duration=atoi(arg); } // Converts a char string to an integer
    else {error=true;}

    if(error==true){

      otto.putMouth(xMouth);
      delay(2000);
      otto.clearMouth();

    }else{

      otto._tone(frec, duration, 1);
    }

    sendFinalAck();

}


//-- Function to receive TRims commands
void receiveTrims(){

    //sendAck & stop if necessary
    sendAck();
    otto.home();

    int trim_YL,trim_YR,trim_RL,trim_RR;

    //Definition of Servo Bluetooth command
    //C trim_YL trim_YR trim_RL trim_RR
    //Examples of receiveTrims Bluetooth commands
    //C 20 0 -8 3
    bool error = false;
    char *arg;
    arg=SCmd.next();
    if (arg != NULL) { trim_YL=atoi(arg); }    // Converts a char string to an integer
    else {error=true;}

    arg = SCmd.next();
    if (arg != NULL) { trim_YR=atoi(arg); }    // Converts a char string to an integer
    else {error=true;}

    arg = SCmd.next();
    if (arg != NULL) { trim_RL=atoi(arg); }    // Converts a char string to an integer
    else {error=true;}

    arg = SCmd.next();
    if (arg != NULL) { trim_RR=atoi(arg); }    // Converts a char string to an integer
    else {error=true;}

    if(error==true){

      otto.putMouth(xMouth);
      delay(2000);
      otto.clearMouth();

    }else{ //Save it on EEPROM
      otto.setTrims(trim_YL, trim_YR, trim_RL, trim_RR);
      otto.saveTrimsOnEEPROM(); //Uncomment this only for one upload when you finaly set the trims.
    }

    sendFinalAck();

}


//-- Function to receive Servo commands
void receiveServo(){

    sendAck();
    moveId = 30;

    //Definition of Servo Bluetooth command
    //G  servo_YL servo_YR servo_RL servo_RR
    //Example of receiveServo Bluetooth commands
    //G 90 85 96 78
    bool error = false;
    char *arg;
    int servo_YL,servo_YR,servo_RL,servo_RR;

    arg=SCmd.next();
    if (arg != NULL) { servo_YL=atoi(arg); }    // Converts a char string to an integer
    else {error=true;}

    arg = SCmd.next();
    if (arg != NULL) { servo_YR=atoi(arg); }    // Converts a char string to an integer
    else {error=true;}

    arg = SCmd.next();
    if (arg != NULL) { servo_RL=atoi(arg); }    // Converts a char string to an integer
    else {error=true;}

    arg = SCmd.next();
    if (arg != NULL) { servo_RR=atoi(arg); }    // Converts a char string to an integer
    else {error=true;}

    if(error==true){

      otto.putMouth(xMouth);
      delay(2000);
      otto.clearMouth();

    }else{ //Update Servo:

      int servoPos[4]={servo_YL, servo_YR, servo_RL, servo_RR};
      otto._moveServos(200, servoPos);   //Move 200ms

    }

    sendFinalAck();

}


//-- Function to receive movement commands
void receiveMovement(){

    sendAck();

    if (otto.getRestState()==true){
        otto.setRestState(false);
    }

    //Definition of Movement Bluetooth commands
    //M  MoveID  T   MoveSize
    char *arg;
    arg = SCmd.next();
    if (arg != NULL) {moveId=atoi(arg);}
    else{
      otto.putMouth(xMouth);
      delay(2000);
      otto.clearMouth();
      moveId=0; //stop
    }

    arg = SCmd.next();
    if (arg != NULL) {T=atoi(arg);}
    else{
      T=1000;
    }

    arg = SCmd.next();
    if (arg != NULL) {moveSize=atoi(arg);}
    else{
      moveSize =15;
    }
}


//-- Function to execute the right movement according the movement command received.
void move(int moveId){

  bool manualMode = false;

  switch (moveId) {
    case 0:
      otto.home();
      break;
    case 1: //M 1 1000
      otto.walk(1,T,1);
      break;
    case 2: //M 2 1000
      otto.walk(1,T,-1);
      break;
    case 3: //M 3 1000
      otto.turn(1,T,1);
      break;
    case 4: //M 4 1000
      otto.turn(1,T,-1);
      break;
    case 5: //M 5 1000 30
      otto.updown(1,T,moveSize);
      break;
    case 6: //M 6 1000 30
      otto.moonwalker(1,T,moveSize,1);
      break;
    case 7: //M 7 1000 30
      otto.moonwalker(1,T,moveSize,-1);
      break;
    case 8: //M 8 1000 30
      otto.swing(1,T,moveSize);
      break;
    case 9: //M 9 1000 30
      otto.crusaito(1,T,moveSize,1);
      break;
    case 10: //M 10 1000 30
      otto.crusaito(1,T,moveSize,-1);
      break;
    case 11: //M 11 1000
      otto.jump(1,T);
      break;
    case 12: //M 12 1000 30
      otto.flapping(1,T,moveSize,1);
      break;
    case 13: //M 13 1000 30
      otto.flapping(1,T,moveSize,-1);
      break;
    case 14: //M 14 1000 20
      otto.tiptoeSwing(1,T,moveSize);
      break;
    case 15: //M 15 500
      otto.bend(1,T,1);
      break;
    case 16: //M 16 500
      otto.bend(1,T,-1);
      break;
    case 17: //M 17 500
      otto.shakeLeg(1,T,1);
      break;
    case 18: //M 18 500
      otto.shakeLeg(1,T,-1);
      break;
    case 19: //M 19 500 20
      otto.jitter(1,T,moveSize);
      break;
    case 20: //M 20 500 15
      otto.ascendingTurn(1,T,moveSize);
      break;
    default:
        manualMode = true;
      break;
  }

  if(!manualMode){
    sendFinalAck();
  }

}


//-- Function to receive gesture commands
void receiveGesture(){

    //sendAck & stop if necessary
    sendAck();
    otto.home();

    //Definition of Gesture Bluetooth commands
    //H  GestureID
    int gesture = 0;
    char *arg;
    arg = SCmd.next();
    if (arg != NULL) {gesture=atoi(arg);}
    else
    {
      otto.putMouth(xMouth);
      delay(2000);
      otto.clearMouth();
    }

    //otto.playGesture(gesture -1);

    switch (gesture) {
      case 1: //H 1
        otto.playGesture(OttoHappy);
        break;
      case 2: //H 2
        otto.playGesture(OttoSuperHappy);
        break;
      case 3: //H 3
        otto.playGesture(OttoSad);
        break;
      case 4: //H 4
        otto.playGesture(OttoSleeping);
        break;
      case 5: //H 5
        otto.playGesture(OttoFart);
        break;
      case 6: //H 6
        otto.playGesture(OttoConfused);
        break;
      case 7: //H 7
        otto.playGesture(OttoLove);
        break;
      case 8: //H 8
        otto.playGesture(OttoAngry);
        break;
      case 9: //H 9
        otto.playGesture(OttoFretful);
        break;
      case 10: //H 10
        otto.playGesture(OttoMagic);
        break;
      case 11: //H 11
        otto.playGesture(OttoWave);
        break;
      case 12: //H 12
        otto.playGesture(OttoVictory);
        break;
      case 13: //H 13
        otto.playGesture(OttoFail);
        break;
      default:
        break;
    }

    sendFinalAck();
}
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

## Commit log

2017-07-20 Modified 3D model for MG90S servos and LedMatrix
    [Head_MATRIX_MG90S.stl, Head_MATRIX_MG90S_v2.stl, OTTO_Body_Matrix_MG90S.stl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]
2018-04-20 The stl files of the original version OTTOPLUS have been deleted. Now there are only the modified files for the version: battery + matrix led + servos MG90S
    [Body_MATRIX_4.stl, Head_MATRIX_5.stl, Head_MATRIX_MG90S.stl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]
